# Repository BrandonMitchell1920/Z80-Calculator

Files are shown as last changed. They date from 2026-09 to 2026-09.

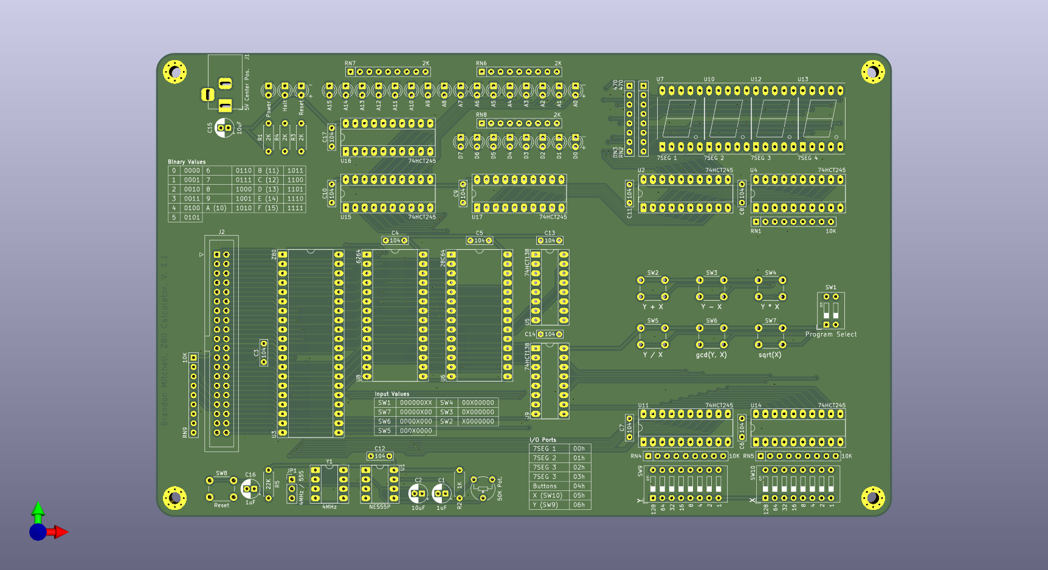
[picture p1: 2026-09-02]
images/PCB No Components.png

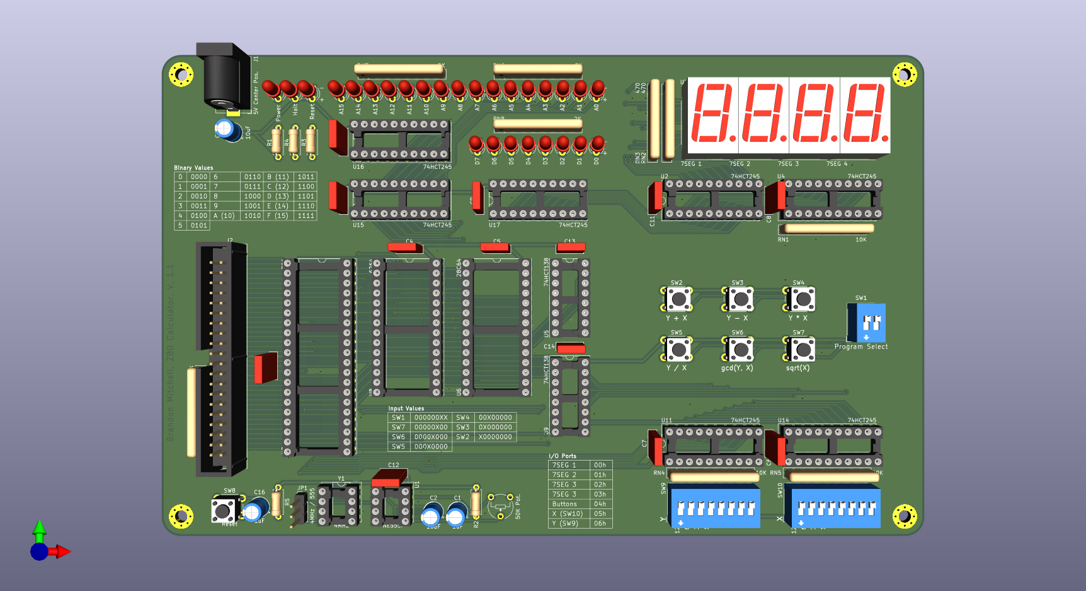
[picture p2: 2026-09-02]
images/PCB With Components.png

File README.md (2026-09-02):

# Z80 Calculator

This is a simple Z80 based calculator.  I have been doing various electronics projects
designed by other people and wanted to try making my own.  I figured a calculator
using the Z80 microprocessor would be a good choice as I had several of them on
hand and could reference other projects if needed.

## Features

The Z80 Caclulator has:

* 8K of RAM
* 8K of ROM
* 2 8-bit inputs (DIP switches)
* 6 push buttons
* Program select switch (software controlled)
* 4 seven segment displays (16-bit output)
* Expansion header for additional RAM or devices
* Blinkenlights!
* 555 timer for variable clock rate (useful for debugging)

Pretty basic, but this was more a learning exercise than anything.  Of the 8K ROM,
only a couple hundred bytes are used.  Combined with the program select switch,
it should be possible to load it up with three other programs.

The answers are displayed in hexadecimal so all operations on two eight bit numbers
would fit on the display.  The following operations are supported:

* Addition
* Subtraction
* Multiplication
* Division
* Greatest common denominator
* Square root

Only integer operations are supported, so division and square root are truncated.

## Programming

The Z80 Calculator has the following memory map:

* ROM: 0x0000 - 0x1FFF
* RAM: 0x2000 - 0x3FFF
* Unused: 0x4000 - 0xFFFF

I/O addresses are the following:

* 7SEG 1: 0x00
* 7SEG 2: 0x01
* 7SEG 3: 0x02
* 7SEG 4: 0x03
* Buttons + Program Select: 0x04
* DIP Switch X: 0x05
* DIP Switch Y: 0x06

The buttons and program select switch are mapped to the following bits of the byte
that you read back from their I/O address:

* SW1: Bits 0 and 1
* SW7: Bit 2
* SW6: Bit 3
* SW5: Bit 4
* SW4: Bit 5
* SW3: Bit 6
* SW2: Bit 7

All inputs are wired up to go high when enabled.  The seven segement displays are
also wired up to go high when a one is written to them.  Only one seven segment
display can be on at any time, and they won't stay on while other calculations
are occuring.  You can see an example of how this works in the provided source code.
There are also predefined values for the addresses and seven segment display values.

The idea with the program select switch was that on boot up, the code would check
what it was set to and jump to a different part of ROM.  However, it could be used
in other ways if multiple programs are not desired.

## BOM

Most of the parts can be had from Mouser except for the Z80 CPU.  Those are easy
enough to find on eBay.  Unicorn Electronics is also a good source for these parts
and is often cheaper than eBay or Mouser.  It might be possible to substitute 74HC
parts for the 74HCT, but I reccomend the latter.  74LS should be fine for any chip
that isn't driving an LED.  To use the 555 timer, you'll need a CMOS Z80.

For getting the PCB, I reccommend JLCPCB.  You can upload the included gerber files
to the site and just use their defaults, though change the color if you want.  Use the
cheapest shipping option (not DHL, FedEx, or UPS).

Component type     | Reference  | Description                                 | Quantity | Notes
------------------ | ---------- | ------------------------------------------- | -------- | --------------------------
PCB                |            | PCB                                         | 1        | JLCPCB, PCBWay
Capacitor          | C1,C16     | 1uF, electrolytic, 2mm lead spacing         | 2        | Could replace with ceramic
Capacitor          | C2,C15     | 10uF, electrolytic, 2mm lead spacing        | 2        | Could replace with ceramic
Capacitor          | C3,C4,C5,C6,C7,C8,C9,C10,C11,C12,C13,C14,C17 | 0.1uF, ceramic, 5mm lead spacing        | 13       |
LED                | D1,D2,D3,D4,D5,D6,D7,D8,D9,D10,D11,D12,D13,D14,D15,D16,D17,D18,D19,D20,D21,D22,D23,D24,D25,D26,D27  | 3mm lead spacing        | 27       | Consider mixing up the colors
Connector          | J1         | Barrel jack, 2.1mm                          | 1        |
Connector          | J2         | 2x20 shrouded pin header                    | 1        | Optional, used for expansion header
Connector          | JP1        | 1x3 pin header                              | 1        |
Resistor           | R1,R3,R4   | 2K ohm                                      | 3        |
Resistor           | R2         | 1K ohm                                      | 1        |
Resistor           | R5         | 22K ohm                                     | 1        |
Resistor Network   | RN1,RN4,RN5,RN9 | 10k ohm, 9 pin bussed                  | 4        |
Resistor Network   | RN2,RN3    | 470 ohm, 8 pin isolated                     | 2        | Could use normal resistors and bend leads
Resistor Network   | RN6,RN7,RN8| 2k ohm, 9 pin bussed                        | 3        |
Potentiometer      | RV1        | 50k ohm                                     | 1        |
Switch             | SW1        | DIP Switch 2x                               | 1        |
Switch             | SW2,SW3,SW4,SW5,SW6,SW7,SW8 | 6mm pushbutton             | 7        |
Switch             | SW9,SW10   | DIP Switch 8x                               | 2        |
IC                 | U1         | NE555P                                      | 1        | Other manufacturers are fine
IC                 | U2,U4,U11,U14,U15,U16,U17 | 74HCT245                     | 7        |
IC                 | U3         | Z80, CMOS, 4MHz                             | 1        |
IC                 | U5,U9      | 74HCT138                                    | 2        |
IC                 | U6         | 28C64 EEPROM                                | 1        | Can use 27C64
IC                 | U7,U10,U12,U13 | Seven segment, common cathode           | 4        | 
IC                 | U8         | 6264 RAM                                    | 1        | 
Oscillator         | Y1         | 4 MHz                                       | 1        | Could use a slower one or a faster one if the CPU supports higher speeds

## Building Firmware

I used RASM to assemble this.  Other assemblers would probably work, but the assembler 
directives may need to change.  Use the command "rasm_w64.exe -ob out.bin main.asm" to assemble.

## Misc

I wrote up a little post to my [blog](https://branmitc.blogspot.com/2026/09/homebrew-z80-computer.html) about designing and building this computer, if you
are interested.

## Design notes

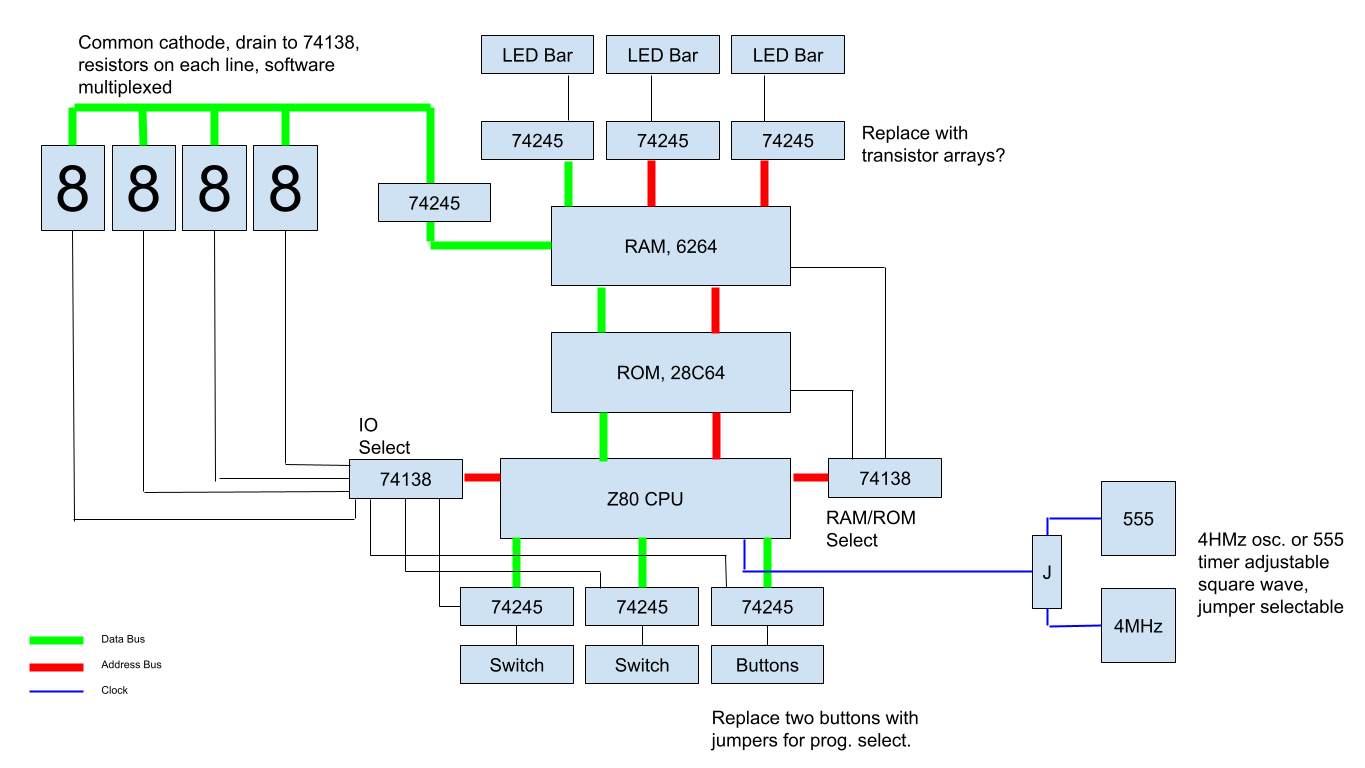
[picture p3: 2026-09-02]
images/Z80 Computer Block Diagram.png

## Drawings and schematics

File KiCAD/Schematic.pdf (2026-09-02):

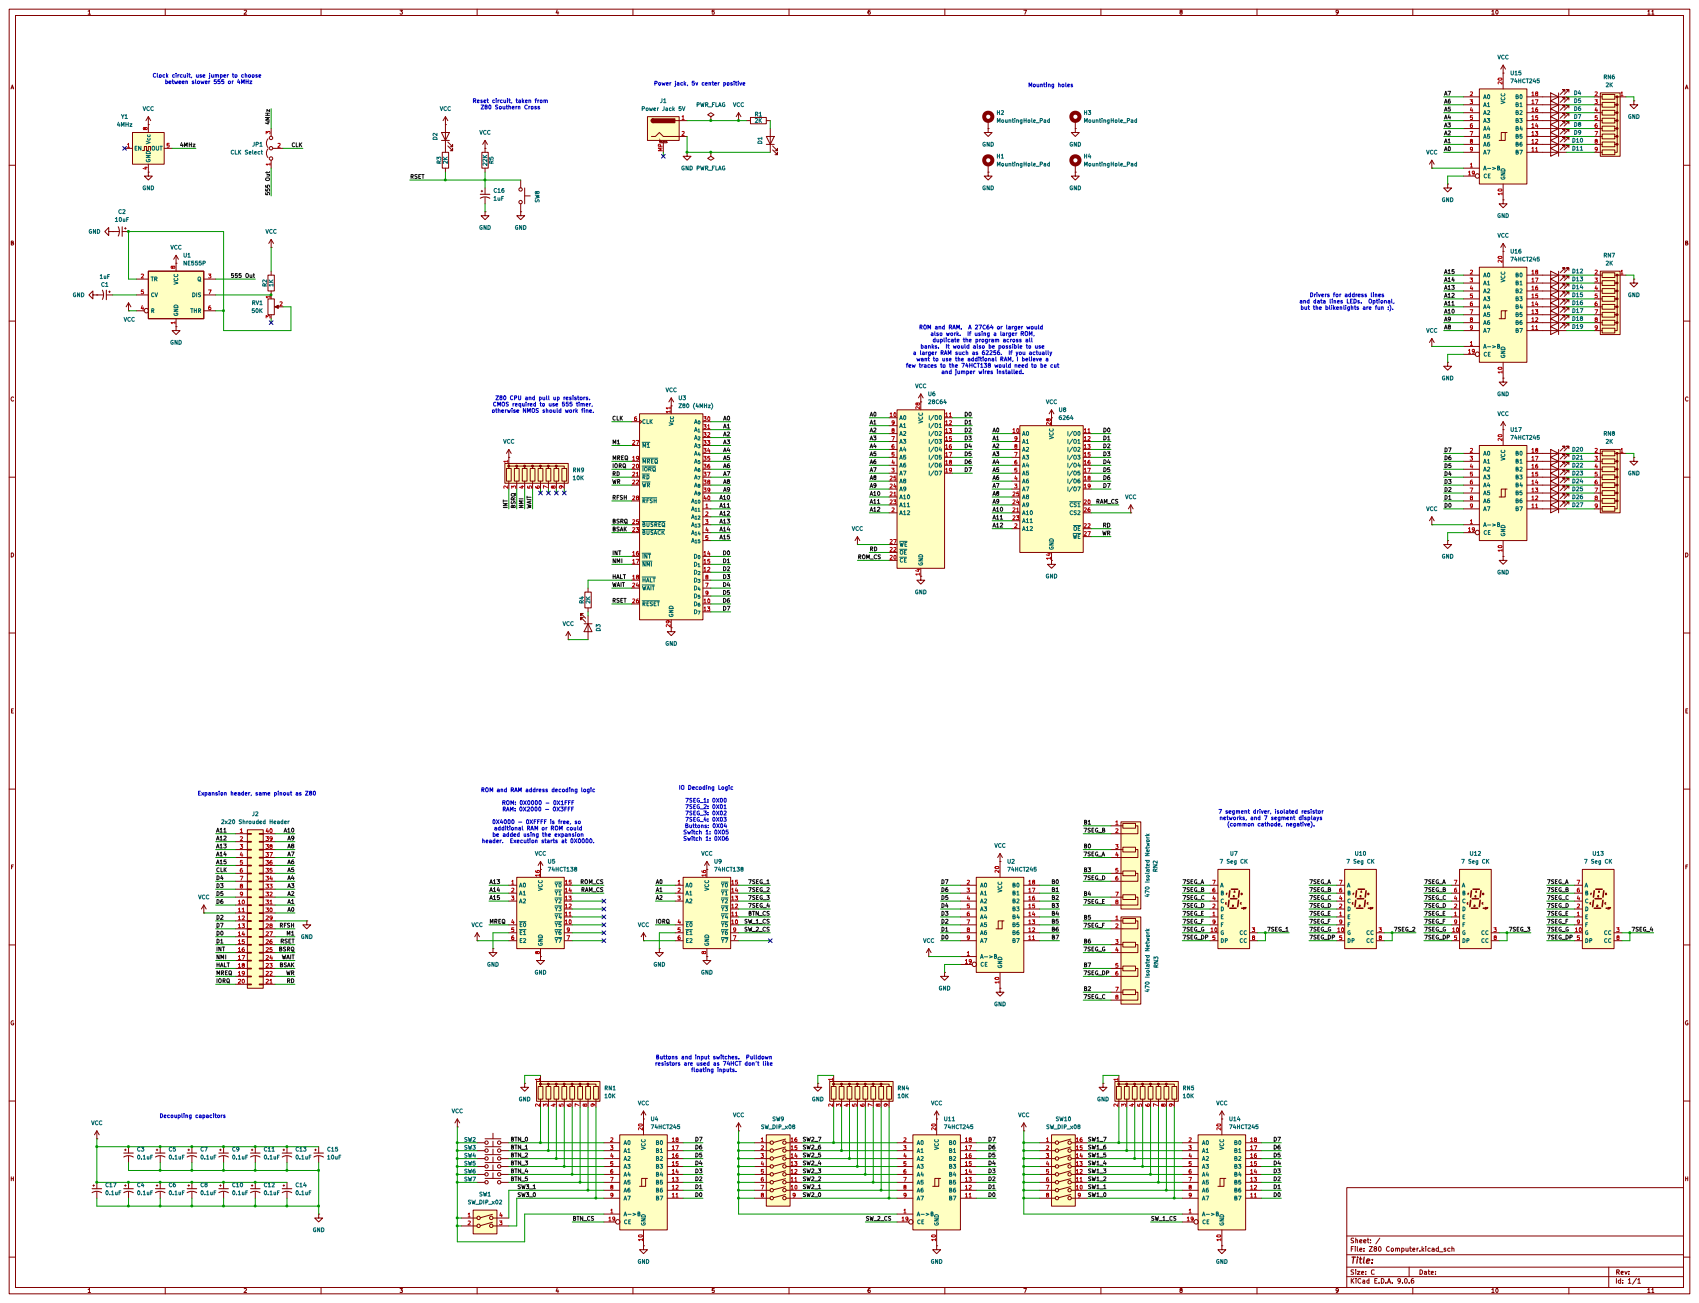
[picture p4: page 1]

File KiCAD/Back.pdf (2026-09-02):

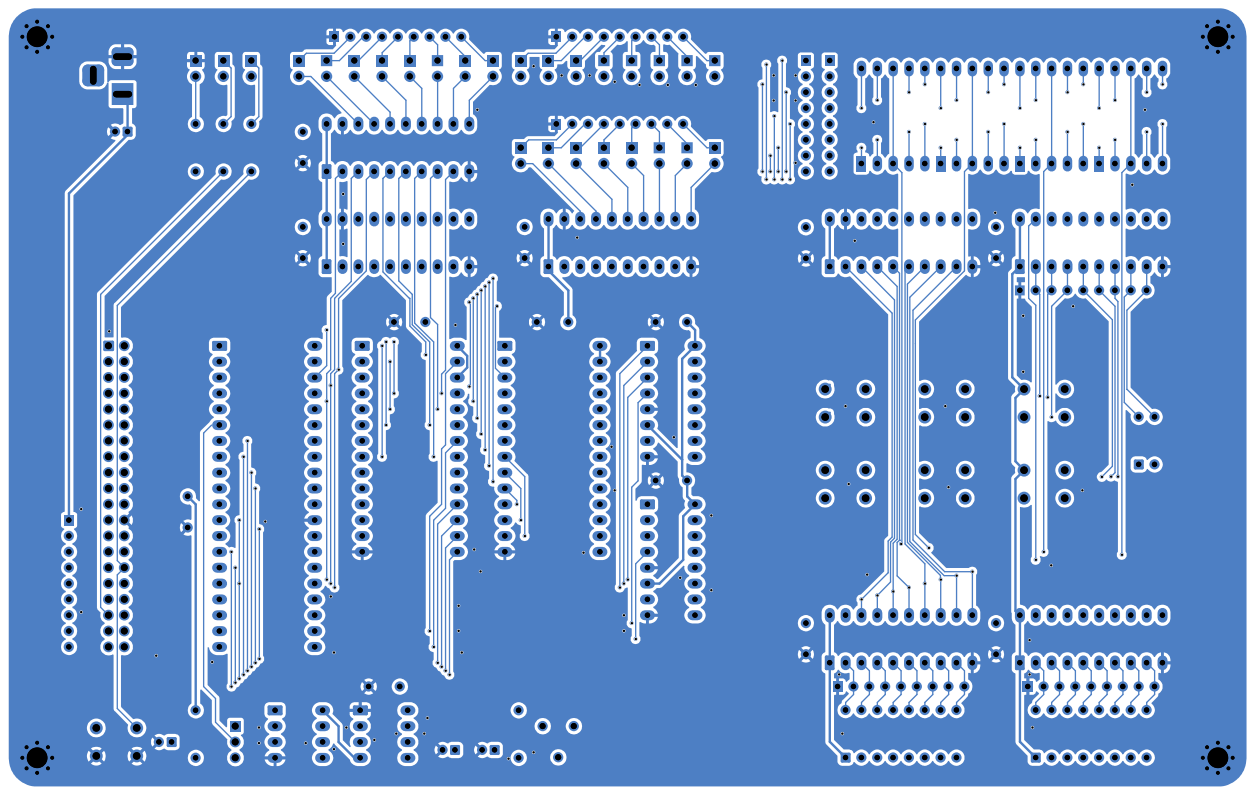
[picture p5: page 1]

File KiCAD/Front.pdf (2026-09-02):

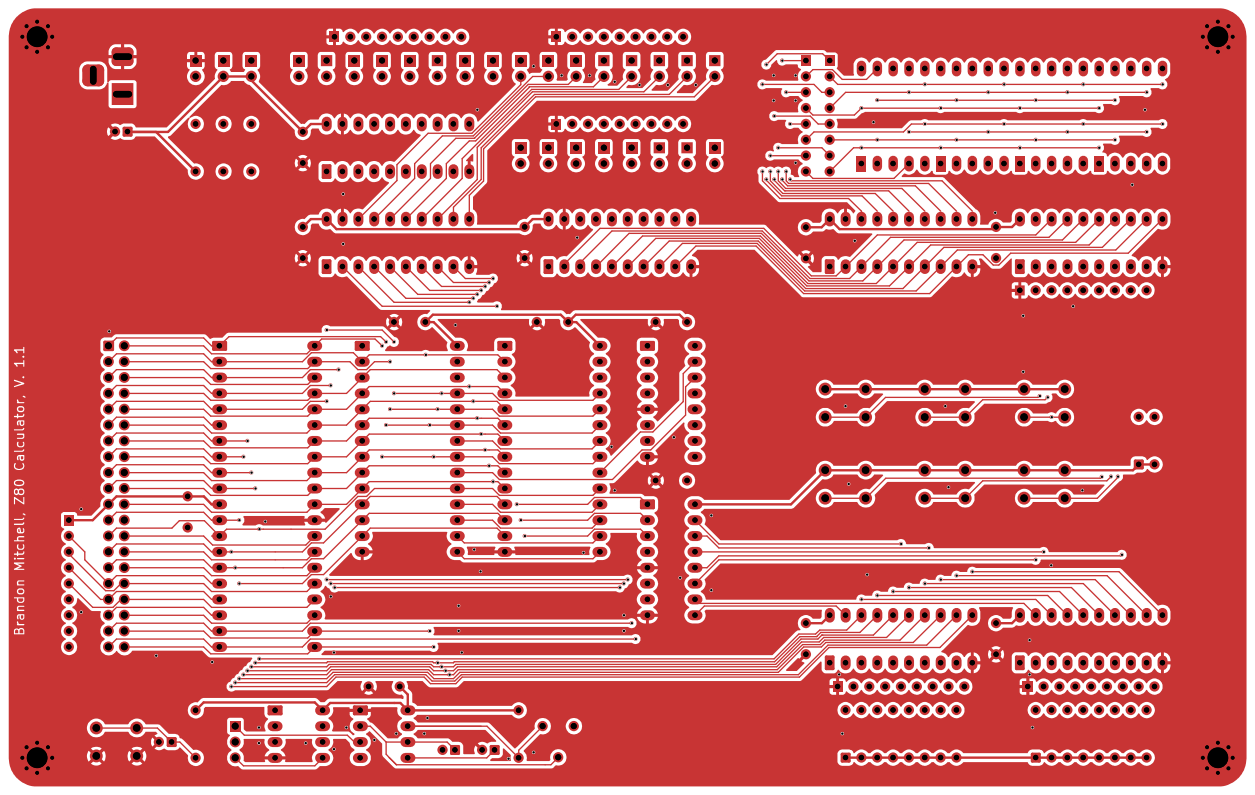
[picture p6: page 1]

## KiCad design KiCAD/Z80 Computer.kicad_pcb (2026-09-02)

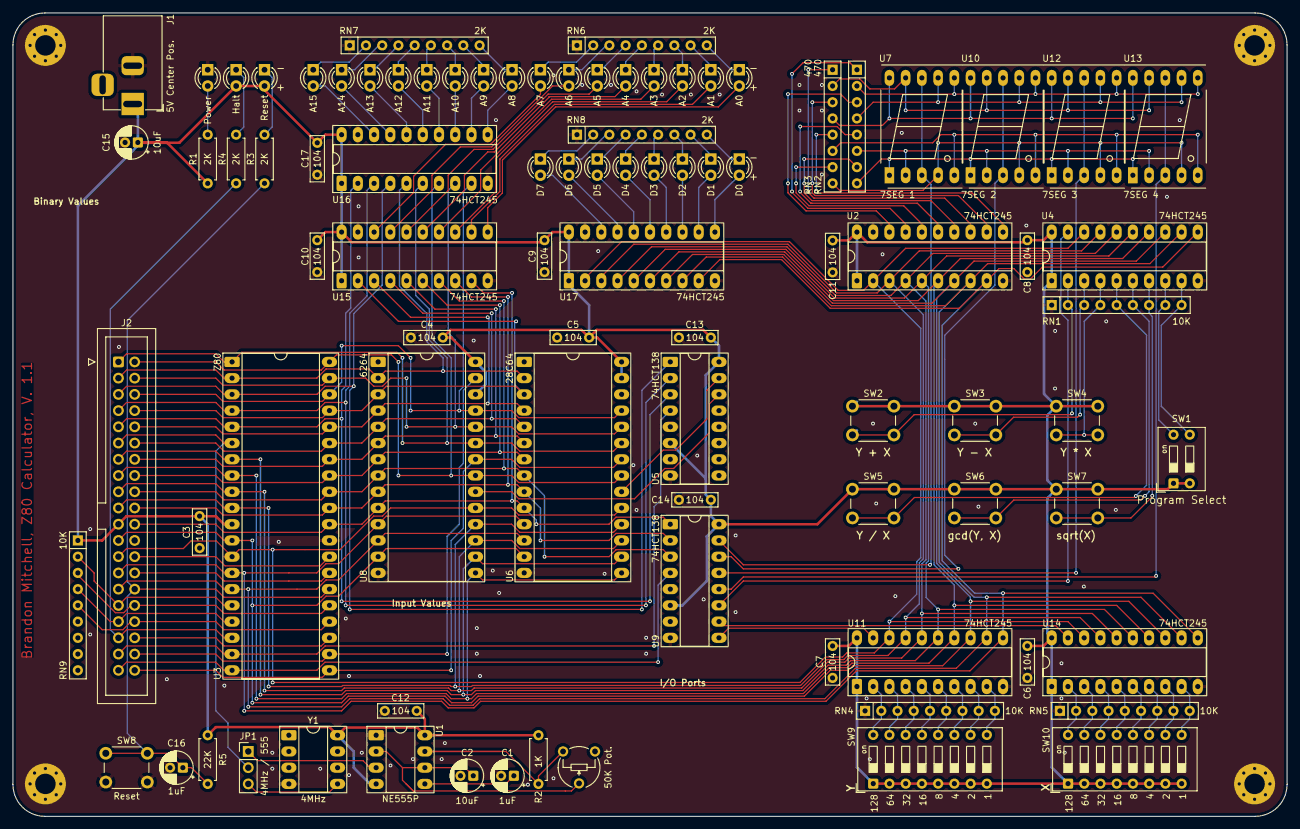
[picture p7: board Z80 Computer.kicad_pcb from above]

Board: 2 copper layers, 199.4 x 125.7 mm, 94 parts (0 on the bottom side), 145 nets.

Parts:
50K Pot.: 50K; Potentiometer_Piher_PT-6-V_Vertical
A0, A1, A2, A3, A4, A5, A6, A7, A8, A9, A10, A11, A12, A13, A14, A15: LED; LED_D3.0mm
C1, C16: 1uF; CP_Radial_D5.0mm_P2.00mm
C2, C15: 10uF; CP_Radial_D5.0mm_P2.00mm
C3, C4, C5, C6, C7, C8, C11, C12, C13, C14, C17: 0.1uF; C_Rect_L7.0mm_W2.0mm_P5.00mm
C9, C10: 104; C_Rect_L7.0mm_W2.0mm_P5.00mm
D0, D1, D2, D3, D4, D5, D6, D7: LED; LED_D3.0mm
H1, H2, H3, H4: MountingHole_Pad; MountingHole_3.2mm_M3_Pad_Via
Halt: LED; LED_D3.0mm
J1: 5V Center Pos.; BarrelJack_Horizontal
J2: 2x20 Shrouded Header; IDC-Header_2x20_P2.54mm_Vertical_Alt
JP1: 4MHz / 555; PinHeader_1x03_P2.54mm_Vertical
Power: LED; LED_D3.0mm
R1, R3, R4: 2K; R_Axial_DIN0207_L6.3mm_D2.5mm_P7.62mm_Horizontal
R2: 1K; R_Axial_DIN0207_L6.3mm_D2.5mm_P7.62mm_Horizontal
R5: 22K; R_Axial_DIN0207_L6.3mm_D2.5mm_P7.62mm_Horizontal
RN1, RN4, RN5, RN9: 10K; R_Array_SIP9
RN2, RN3: 100 Isolated Network; R_Array_SIP8
RN6, RN7, RN8: 2K; R_Array_SIP9
Reset: LED; LED_D3.0mm
SW1: Program Select; SW_DIP_SPSTx02_Slide_9.78x7.26mm_W7.62mm_P2.54mm
SW2: Y + X; SW_PUSH_6mm
SW3: Y - X; SW_PUSH_6mm
SW4: Y * X; SW_PUSH_6mm
SW5: Y / X; SW_PUSH_6mm
SW6: gcd(Y, X); SW_PUSH_6mm
SW7: sqrt(X); SW_PUSH_6mm
SW8: Reset; SW_PUSH_6mm
SW9, SW10: SW_DIP_x08; SW_DIP_SPSTx08_Slide_9.78x22.5mm_W7.62mm_P2.54mm
U1: NE555P; DIP-8_W7.62mm_Socket_LongPads
U2, U4, U11, U14, U15, U16, U17: 74HCT245; DIP-20_W7.62mm_Socket_LongPads
U3: Z80; DIP-40_W15.24mm_Socket_LongPads
U5, U9: 74HCT138; DIP-16_W7.62mm_Socket_LongPads
U6: 28C64; DIP-28_W15.24mm_Socket_LongPads
U7, U10, U12, U13: 7 Seg CK; 7SegmentLED_LTS6760_LTS6780
U8: 6264; DIP-28_W15.24mm_Socket_LongPads
Y1: 4MHz; DIP-8_W7.62mm_Socket_LongPads

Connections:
/4MHz: JP1.3 (B), Y1.5 (OUT)
/7SEG_1: U7.3 (CC), U7.8 (CC), U9.15 (~Y0)
/7SEG_2: U9.14 (~Y1), U10.3 (CC), U10.8 (CC)
/7SEG_3: U9.13 (~Y2), U12.3 (CC), U12.8 (CC)
/7SEG_4: U9.12 (~Y3), U13.3 (CC), U13.8 (CC)
/7SEG_A: RN2.4 (R2.2), U7.7 (A), U10.7 (A), U12.7 (A), U13.7 (A)
/7SEG_B: RN2.2 (R1.2), U7.6 (B), U10.6 (B), U12.6 (B), U13.6 (B)
/7SEG_C: RN3.8 (R4.2), U7.4 (C), U10.4 (C), U12.4 (C), U13.4 (C)
/7SEG_D: RN2.6 (R3.2), U7.2 (D), U10.2 (D), U12.2 (D), U13.2 (D)
/7SEG_DP: RN3.6 (R3.2), U7.5 (DP), U10.5 (DP), U12.5 (DP), U13.5 (DP)
/7SEG_E: RN2.8 (R4.2), U7.1 (E), U10.1 (E), U12.1 (E), U13.1 (E)
/7SEG_F: RN3.2 (R1.2), U7.9 (F), U10.9 (F), U12.9 (F), U13.9 (F)
/7SEG_G: RN3.4 (R2.2), U7.10 (G), U10.10 (G), U12.10 (G), U13.10 (G)
/555 Out: JP1.1 (A), U1.3 (Q)
/A0: J2.30, U3.30 (A_{0}), U6.10 (A0), U8.10 (A0), U9.1 (A0), U15.9 (A7)
/A1: J2.31, U3.31 (A_{1}), U6.9 (A1), U8.9 (A1), U9.2 (A1), U15.8 (A6)
/A2: J2.32, U3.32 (A_{2}), U6.8 (A2), U8.8 (A2), U9.3 (A2), U15.7 (A5)
/A3: J2.33, U3.33 (A_{3}), U6.7 (A3), U8.7 (A3), U15.6 (A4)
/A4: J2.34, U3.34 (A_{4}), U6.6 (A4), U8.6 (A4), U15.5 (A3)
/A5: J2.35, U3.35 (A_{5}), U6.5 (A5), U8.5 (A5), U15.4 (A2)
/A6: J2.36, U3.36 (A_{6}), U6.4 (A6), U8.4 (A6), U15.3 (A1)
/A7: J2.37, U3.37 (A_{7}), U6.3 (A7), U8.3 (A7), U15.2 (A0)
/A8: J2.38, U3.38 (A_{8}), U6.25 (A8), U8.25 (A8), U16.9 (A7)
/A9: J2.39, U3.39 (A_{9}), U6.24 (A9), U8.24 (A9), U16.8 (A6)
/A10: J2.40, U3.40 (A_{10}), U6.21 (A10), U8.21 (A10), U16.7 (A5)
/A11: J2.1, U3.1 (A_{11}), U6.23 (A11), U8.23 (A11), U16.6 (A4)
/A12: J2.2, U3.2 (A_{12}), U6.2 (A12), U8.2 (A12), U16.5 (A3)
/A13: J2.3, U3.3 (A_{13}), U5.1 (A0), U16.4 (A2)
/A14: J2.4, U3.4 (A_{14}), U5.2 (A1), U16.3 (A1)
/A15: J2.5, U3.5 (A_{15}), U5.3 (A2), U16.2 (A0)
/B0: RN2.3 (R2.1), U2.18 (B0)
/B1: RN2.1 (R1.1), U2.17 (B1)
/B2: RN3.7 (R4.1), U2.16 (B2)
/B3: RN2.5 (R3.1), U2.15 (B3)
/B4: RN2.7 (R4.1), U2.14 (B4)
/B5: RN3.1 (R1.1), U2.13 (B5)
/B6: RN3.3 (R2.1), U2.12 (B6)
/B7: RN3.5 (R3.1), U2.11 (B7)
/BSAK: J2.23, U3.23 (~BUSACK)
/BSRQ: J2.25, RN9.3 (R2), U3.25 (~BUSREQ)
/BTN_0: RN1.2 (R1), SW2.2, U4.2 (A0)
/BTN_1: RN1.3 (R2), SW3.2, U4.3 (A1)
/BTN_2: RN1.4 (R3), SW4.2, U4.4 (A2)
/BTN_3: RN1.5 (R4), SW5.2, U4.5 (A3)
/BTN_4: RN1.6 (R5), SW6.2, U4.6 (A4)
/BTN_5: RN1.7 (R6), SW7.2, U4.7 (A5)
/BTN_CS: U4.19 (CE), U9.11 (~Y4)
/CLK: J2.6, JP1.2 (C), U3.6 (CLK)
/D0: J2.14, U2.9 (A7), U3.14 (D_{0}), U4.11 (B7), U6.11 (I/O0), U8.11 (I/O0), U11.11 (B7), U14.11 (B7), U17.9 (A7)
/D1: J2.15, U2.8 (A6), U3.15 (D_{1}), U4.12 (B6), U6.12 (I/O1), U8.12 (I/O1), U11.12 (B6), U14.12 (B6), U17.8 (A6)
/D2: J2.12, U2.7 (A5), U3.12 (D_{2}), U4.13 (B5), U6.13 (I/O2), U8.13 (I/O2), U11.13 (B5), U14.13 (B5), U17.7 (A5)
/D3: J2.8, U2.6 (A4), U3.8 (D_{3}), U4.14 (B4), U6.15 (I/O3), U8.15 (I/O3), U11.14 (B4), U14.14 (B4), U17.6 (A4)
/D4: J2.7, U2.5 (A3), U3.7 (D_{4}), U4.15 (B3), U6.16 (I/O4), U8.16 (I/O4), U11.15 (B3), U14.15 (B3), U17.5 (A3)
/D5: J2.9, U2.4 (A2), U3.9 (D_{5}), U4.16 (B2), U6.17 (I/O5), U8.17 (I/O5), U11.16 (B2), U14.16 (B2), U17.4 (A2)
/D6: J2.10, U2.3 (A1), U3.10 (D_{6}), U4.17 (B1), U6.18 (I/O6), U8.18 (I/O6), U11.17 (B1), U14.17 (B1), U17.3 (A1)
/D7: J2.13, U2.2 (A0), U3.13 (D_{7}), U4.18 (B0), U6.19 (I/O7), U8.19 (I/O7), U11.18 (B0), U14.18 (B0), U17.2 (A0)
/HALT: J2.18, R4.1, U3.18 (~HALT)
/INT: J2.16, RN9.2 (R1), U3.16 (~INT)
/IORQ: J2.20, U3.20 (~IORQ), U9.4 (~E0)
/M1: J2.27, U3.27 (~M1)
/MREQ: J2.19, U3.19 (~MREQ), U5.4 (~E0)
/NMI: J2.17, RN9.4 (R3), U3.17 (~NMI)
/RAM_CS: U5.14 (~Y1), U8.20 (~CS1)
/RD: J2.21, U3.21 (~RD), U6.22 (~OE), U8.22 (~OE)
/RFSH: J2.28, U3.28 (~RFSH)
/ROM_CS: U5.15 (~Y0), U6.20 (~CE)
/RSET: C16.1, J2.26, R3.2, R5.2, SW8.1, U3.26 (~RESET)
/SW1_0: RN5.9 (R8), SW10.9, U14.9 (A7)
/SW1_1: RN5.8 (R7), SW10.10, U14.8 (A6)
/SW1_2: RN5.7 (R6), SW10.11, U14.7 (A5)
/SW1_3: RN5.6 (R5), SW10.12, U14.6 (A4)
/SW1_4: RN5.5 (R4), SW10.13, U14.5 (A3)
/SW1_5: RN5.4 (R3), SW10.14, U14.4 (A2)
/SW1_6: RN5.3 (R2), SW10.15, U14.3 (A1)
/SW1_7: RN5.2 (R1), SW10.16, U14.2 (A0)
/SW2_0: RN4.9 (R8), SW9.9, U11.9 (A7)
/SW2_1: RN4.8 (R7), SW9.10, U11.8 (A6)
/SW2_2: RN4.7 (R6), SW9.11, U11.7 (A5)
/SW2_3: RN4.6 (R5), SW9.12, U11.6 (A4)
/SW2_4: RN4.5 (R4), SW9.13, U11.5 (A3)
/SW2_5: RN4.4 (R3), SW9.14, U11.4 (A2)
/SW2_6: RN4.3 (R2), SW9.15, U11.3 (A1)
/SW2_7: RN4.2 (R1), SW9.16, U11.2 (A0)
/SW3_0: RN1.9 (R8), SW1.3, U4.9 (A7)
/SW3_1: RN1.8 (R7), SW1.4, U4.8 (A6)
/SW_1_CS: U9.10 (~Y5), U14.19 (CE)
/SW_2_CS: U9.9 (~Y6), U11.19 (CE)
/WAIT: J2.24, RN9.5 (R4), U3.24 (~WAIT)
/WR: J2.22, U3.22 (~WR), U8.27 (~WE)
GND: C1.2, C2.2, C3.2, C4.2, C5.2, C6.2, C7.2, C8.2, C9.2, C10.2, C11.2, C12.2, C13.2, C14.2, C15.2, C16.2, C17.2, H1.1, H2.1, H3.1, H4.1, J1.2, J2.29, Power.1 (K), RN1.1 (common), RN4.1 (common), RN5.1 (common), RN6.1 (common), RN7.1 (common), RN8.1 (common), SW8.2, U1.1 (GND), U2.10 (GND), U2.19 (CE), U3.29 (GND), U4.10 (GND), U5.5 (~E1), U5.8 (GND), U6.14 (GND), U8.14 (GND), U9.5 (~E1), U9.8 (GND), U11.10 (GND), U14.10 (GND), U15.10 (GND), U15.19 (CE), U16.10 (GND), U16.19 (CE), U17.10 (GND), U17.19 (CE), Y1.4 (GND)
unnamed: Power.2 (A), R1.1
unnamed: R3.1, Reset.1 (K)
unnamed: Halt.1 (K), R4.2
unnamed: A7.2 (A), U15.18 (B0)
unnamed: A7.1 (K), RN6.2 (R1)
unnamed: A6.2 (A), U15.17 (B1)
unnamed: A6.1 (K), RN6.3 (R2)
unnamed: A5.2 (A), U15.16 (B2)
unnamed: A5.1 (K), RN6.4 (R3)
unnamed: A4.2 (A), U15.15 (B3)
unnamed: A4.1 (K), RN6.5 (R4)
unnamed: A3.2 (A), U15.14 (B4)
unnamed: A3.1 (K), RN6.6 (R5)
unnamed: A2.2 (A), U15.13 (B5)
unnamed: A2.1 (K), RN6.7 (R6)
unnamed: A1.2 (A), U15.12 (B6)
unnamed: A1.1 (K), RN6.8 (R7)
unnamed: A0.2 (A), U15.11 (B7)
unnamed: A0.1 (K), RN6.9 (R8)
unnamed: A15.2 (A), U16.18 (B0)
unnamed: A15.1 (K), RN7.2 (R1)
unnamed: A14.2 (A), U16.17 (B1)
unnamed: A14.1 (K), RN7.3 (R2)
unnamed: A13.2 (A), U16.16 (B2)
unnamed: A13.1 (K), RN7.4 (R3)
unnamed: A12.2 (A), U16.15 (B3)
unnamed: A12.1 (K), RN7.5 (R4)
unnamed: A11.2 (A), U16.14 (B4)
unnamed: A11.1 (K), RN7.6 (R5)
unnamed: A10.2 (A), U16.13 (B5)
unnamed: A10.1 (K), RN7.7 (R6)
unnamed: A9.2 (A), U16.12 (B6)
unnamed: A9.1 (K), RN7.8 (R7)
unnamed: A8.2 (A), U16.11 (B7)
unnamed: A8.1 (K), RN7.9 (R8)
unnamed: D7.2 (A), U17.18 (B0)
unnamed: D7.1 (K), RN8.2 (R1)
unnamed: D6.2 (A), U17.17 (B1)
unnamed: D6.1 (K), RN8.3 (R2)
unnamed: D5.2 (A), U17.16 (B2)
unnamed: D5.1 (K), RN8.4 (R3)
unnamed: D4.2 (A), U17.15 (B3)
unnamed: D4.1 (K), RN8.5 (R4)
unnamed: D3.2 (A), U17.14 (B4)
unnamed: D3.1 (K), RN8.6 (R5)
unnamed: D2.2 (A), U17.13 (B5)
unnamed: D2.1 (K), RN8.7 (R6)
unnamed: D1.2 (A), U17.12 (B6)
unnamed: D1.1 (K), RN8.8 (R7)
unnamed: D0.2 (A), U17.11 (B7)
unnamed: D0.1 (K), RN8.9 (R8)
unnamed: C1.1, U1.5 (CV)
unnamed: 50K Pot..1, R2.1, U1.7 (DIS)
unnamed: 50K Pot..2, C2.1, U1.2 (TR), U1.6 (THR)
VCC: C3.1, C4.1, C5.1, C6.1, C7.1, C8.1, C9.1, C10.1, C11.1, C12.1, C13.1, C14.1, C15.1, C17.1, Halt.2 (A), J1.1, J2.11, R1.2, R2.2, R5.1, RN9.1 (common), Reset.2 (A), SW1.1, SW1.2, SW2.1, SW3.1, SW4.1, SW5.1, SW6.1, SW7.1, SW9.1, SW9.2, SW9.3, SW9.4, SW9.5, SW9.6, SW9.7, SW9.8, SW10.1, SW10.2, SW10.3, SW10.4, SW10.5, SW10.6, SW10.7, SW10.8, U1.4 (R), U1.8 (VCC), U2.1 (A->B), U2.20 (VCC), U3.11 (V_{CC}), U4.1 (A->B), U4.20 (VCC), U5.6 (E2), U5.16 (VCC), U6.27 (~WE), U6.28 (VCC), U8.26 (CS2), U8.28 (VCC), U9.6 (E2), U9.16 (VCC), U11.1 (A->B), U11.20 (VCC), U14.1 (A->B), U14.20 (VCC), U15.1 (A->B), U15.20 (VCC), U16.1 (A->B), U16.20 (VCC), U17.1 (A->B), U17.20 (VCC), Y1.8 (Vcc)

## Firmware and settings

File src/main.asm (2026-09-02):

; Z80 Calculator Program
; Brandon Mitchell
; rasm_w64.exe -ob out.bin main.asm
; http://rasm.wikidot.com/

; I/O addresses, 7 segement is output only, buttons and switches are input only
CS_7SEG_1       equ 0x00
CS_7SEG_2       equ 0x01
CS_7SEG_3       equ 0x02
CS_7SEG_4       equ 0x03
CS_BTN          equ 0x04
CS_SW_X         equ 0x05
CS_SW_Y         equ 0x06

; Used for checking which button was pressed, each button is tied to one data line
BIT_ADD         equ 7
BIT_SUB         equ 6
BIT_MUL         equ 5
BIT_DIV         equ 4
BIT_GCD         equ 3
BIT_SQRT        equ 2

; 7 6 5 4 3 2 1 0
; A B C D E F G DP
VAL_0           equ 0b11111100
VAL_1           equ 0b01100000
VAL_2           equ 0b11011010
VAL_3           equ 0b11110010
VAL_4           equ 0b01100110
VAL_5           equ 0b10110110
VAL_6           equ 0b10111110
VAL_7           equ 0b11100000
VAL_8           equ 0b11111110
VAL_9           equ 0b11110110
VAL_A           equ 0b11101110
VAL_B           equ 0b00111110
VAL_C           equ 0b10011100
VAL_D           equ 0b01111010
VAL_E           equ 0b10011110
VAL_F           equ 0b10001110

VAL_HYPHEN      equ 0b00000010

; Blank and r are used to display " Err", used when dividing by 0
VAL_BLANK       equ 0b00000000
VAL_r           equ 0b00001010

; Location of the display_ans values in ROM
VAL_START       equ 0x0200
SQRT_START      equ 0x0210

; 0000 - 1FFF is ROM, 2000 - 3FFF is RAM
RAM_START       equ 0x2000

; Memory locations of a view variables, used in display routine
NEG_RES         equ 0x2000
ANS_LOW         equ 0x2001
ANS_HIGH        equ 0x2002
DISP_SEG_1      equ 0x2003
DISP_SEG_2      equ 0x2004
DISP_SEG_3      equ 0x2005
DISP_SEG_4      equ 0x2006

; We want to store these values in ROM for use as a look up table
org             VAL_START
defb            VAL_0, VAL_1, VAL_2, VAL_3, VAL_4, VAL_5, VAL_6, VAL_7, VAL_8, VAL_9, VAL_A, VAL_B, VAL_C, VAL_D, VAL_E, VAL_F

; I didn't want to implement an actual square root, so store squares from 0 to 15
; We can then just consult this table to find which is closest to the input
org             SQRT_START
defb            0, 1, 4, 9, 16, 25, 36, 49, 64, 81, 100, 121, 144, 169, 196, 225

; Reset address to beginning of address space
org             0x0000



startup:
    ld          a, 0x00                 ; Clear neg bit
    ld          (NEG_RES), a

    ld          a, VAL_0                ; Screen should display all zeroes on start up
    ld          (DISP_SEG_1), a
    ld          (DISP_SEG_2), a
    ld          (DISP_SEG_3), a
    ld          (DISP_SEG_4), a



mainloop:
    in          a, (CS_BTN)             ; Read the buttons

    bit         BIT_ADD, a              ; Check which button was pressed
    jp          nz, addition

    bit         BIT_SUB, a
    jp          nz, subtraction

    bit         BIT_MUL, a
    jp          nz, multiplication

    bit         BIT_DIV, a
    jp          nz, divide

    bit         BIT_GCD, a
    jp          nz, gcd

    bit         BIT_SQRT, a
    jp          nz, square_root

    jp          display_ans             ; Display the answer



addition:
    ld          a, 0x00                 ; Clear neg bit
    ld          (NEG_RES), a

    in          a, (CS_SW_Y)            ; Read Y switch into A
    ld          h, 0x00                 ; Clear out H register (upper half of HL)
    ld          l, a                    ; L = A

    in          a, (CS_SW_X)            ; Read X switch into A
    ld          b, 0x00                 ; Clear out B register (upper half of BC)
    ld          c, a                    ; C = A

    add         hl, bc                  ; Needed to clear upper bytes as we are doing a 16 bit add

    ld          (ANS_LOW), hl           ; Store in RAM for later use

    jp          format_ans              ; Format the answer for later display



subtraction:
    ld          a, 0x00                 ; Clear neg bit
    ld          (NEG_RES), a

    in          a, (CS_SW_X)            ; Read X switch into A
    ld          c, a                    ; Move A value to C

    in          a, (CS_SW_Y)            ; Read Y switch into A

    cp          c                       ; Compare A and C
    jp          nc, subtraction_pos     ; If carry flag is not set, then A >= C, skip negative handling code

    ld          b, c                    ; Swap A with C before doing subtraction as A < C
    ld          c, a

    ld          a, 0x01                 ; Set neg bit
    ld          (NEG_RES), a

    ld          a, b                    ; Save C's value to A

subtraction_pos:
    sub         c                       ; A = A - C

    ld          (ANS_LOW), a            ; Save result for later
    ld          a, 0x00
    ld          (ANS_HIGH), a           ; The upper 8 bytes will always be 00 as the difference between two 8 bit
                                        ; values will always be an 8 bit value
    jp          format_ans              ; Format the answer for later display



multiplication:
    ld          a, 0x00                 ; Clear neg bit
    ld          (NEG_RES), a

    ld          l, a                    ; Clear out HL, will be used for adding
    ld          h, a

    in          a, (CS_SW_Y)            ; Read Y switch into A
    ld          b, 0x00                 ; Clear out B register (upper half of BC)
    ld          c, a                    ; C = A

    in          a, (CS_SW_X)            ; Read X switch into A

    cp          c                       ; Compare A and C
    jp          c, multiplication_loop  ; If carry flag is set, then A < C, go to loop

    ld          e, a                    ; Else, swap the values so the multiplication is faster
    ld          a, c
    ld          c, e

multiplication_loop:
    and         a                       ; Check if a is zero and exit loop if so
    jp          z, multiplication_end

    add         hl, bc                  ; Else, perform the add
    dec         a                       ; A is our loop counter, decrement it
    jp          multiplication_loop

multiplication_end:
    ld          (ANS_LOW), hl           ; Store in RAM for later use

    jp          format_ans              ; Format the answer for later display



divide:
    ld          a, 0x00                 ; Clear neg bit
    ld          (NEG_RES), a

    in          a, (CS_SW_X)            ; Read X switch into A

    and         a                       ; If it is zero, display an error
    jp          z, format_err           ; Can't divide by zero

    ld          c, a                    ; Move A value to C

    in          a, (CS_SW_Y)            ; Read Y switch into A

    ld          e, 0x00                 ; Used to store our answer

divide_loop:
    cp          c,                      ; A < C, stop division
    jp          c, divide_end

    sub         c                       ; A = A - C
    inc         e                       ; Increment our answer

    jp          divide_loop

divide_end:
    ld          a, e                    ; Load answer into A register
    ld          (ANS_LOW), a            ; Save result in RAM for later
    ld          a, 0x00                 ; The upper byte will always be 00
    ld          (ANS_HIGH), a

    jp          format_ans              ; Format the answer for later display



gcd:                                    ; Euclid's algorithm using subtraction
    ld          a, 0x00                 ; Clear neg bit
    ld          (NEG_RES), a

    in          a, (CS_SW_X)            ; Read X switch into A
    ld          c, a                    ; Move A value to C

    in          a, (CS_SW_Y)            ; Read Y switch into A
    ld          e, a                    ; Move A value to E

    and         a                       ; Test if E is zero
    jp          z, gcd_end              ; If so, skip to end, C is the answer

    ld          a, c                    ; Check if C is zero
    and         a
    jp          z, gcd_e_end            ; Skip to end and load E as answer

gcd_loop:
    ld          a, c                    ; Load C into A ...
    cp          e                       ; ... so we can compare it to E

    jp          z, gcd_end              ; C == E, we have our answer

    jp          nc, gcd_greater_than    ; C >= E

    ld          a, e                    ; Load E into A so we can perform the subtraction
    sub         c                       ; A = A - C
    ld          e, a                    ; E = A

    jp          gcd_loop

gcd_greater_than:
    ld          a, c                    ; Load E into A so we can perform the subtraction
    sub         e                       ; A = A - E
    ld          c, a                    ; C = A

    jp          gcd_loop

gcd_e_end:
    ld          c, e

gcd_end:
    ld          a, c                    ; Load answer into A register
    ld          (ANS_LOW), a            ; Save result for later
    ld          a, 0x00                 ; The upper byte will always be 00
    ld          (ANS_HIGH), a

    jp          format_ans              ; Format the answer for later display



square_root:
    ld          a, 0x00                 ; Clear neg bit
    ld          (NEG_RES), a

    in          a, (CS_SW_X)            ; Read X switch into A

    ld          b, 0x00                 ; Clear out B, upper half of BC
    ld          c, 15                   ; Highest possible int

square_root_loop:
    ld          hl, SQRT_START          ; Load in our ROM start value
    add         hl, bc                  ; Add to it our offset

    cp          (HL)                    ; Perform the comparision
    jp          nc, square_root_end     ; A >= (HL), we have our answer

    dec         c                       ; Decrement our offset and try again

    jp          square_root_loop

square_root_end:
    ld          a, c                    ; Load answer into A register
    ld          (ANS_LOW), a            ; Save result in RAM for later
    ld          a, 0x00                 ; The upper byte will always be 00    
    ld          (ANS_HIGH), a

    jp          format_ans              ; Format the answer for later display



format_err:
    ld          a, VAL_BLANK            ; Display " Err" for divide by 0
    ld          (DISP_SEG_1), a         ; Load appropriate values into RAM

    ld          a, VAL_E
    ld          (DISP_SEG_2), a

    ld          a, VAL_r
    ld          (DISP_SEG_3), a
    ld          (DISP_SEG_4), a

    jp          display_ans             ; Display the answer



format_ans:
    ld          b, 0x00                 ; B is used in getting the RAM offset, need to clear it

    ld          a, (ANS_LOW)            ; Load in the lower half of the answer
    and         0x0F                    ; We want the lower nibble for use as an offset

    ld          hl, VAL_START           ; Load in our ROM address
    ld          c, a                    ; and move the offset to C
    add         hl, bc                  ; and add to get the ROM address

    ld          a, (hl)                 ; Load the correct value
    ld          (DISP_SEG_4), a         ; and save it for later display

    ld          a, (ANS_LOW)            ; Perform same steps with upper nibble
    rrca        4                       ; Rotate right four times to isolate upper nibble
    and         0x0F

    ld          hl, VAL_START
    ld          c, a
    add         hl, bc

    ld          a, (hl)
    ld          (DISP_SEG_3), a

    out         (CS_7SEG_3), a

    ld          a, (ANS_HIGH)
    and         0x0F

    ld          hl, VAL_START
    ld          c, a
    add         hl, bc

    ld          a, (hl)
    ld          (DISP_SEG_2), a

    ld          a, (NEG_RES)            ; Check if neg bit is set
    and         a

    jp          nz, format_ans_neg      ; Skip logic for finding hex value, just show hyphen if negative

    ld          a, (ANS_HIGH)           ; Otherwise, perform same lookup logic
    rrca        4
    and         0x0F

    ld          hl, VAL_START
    ld          c, a
    add         hl, bc

    ld          a, (hl)
    ld          (DISP_SEG_1), a

    jp          display_ans

format_ans_neg:

    ld          a, VAL_HYPHEN           ; Load a hyphen into the first digit
    ld          (DISP_SEG_1), a

    jp          display_ans



display_ans:
    ld          a, (DISP_SEG_1)         ; Load first character and display it
    out         (CS_7SEG_1), a

    ld          a, (DISP_SEG_2)
    out         (CS_7SEG_2), a

    ld          a, (DISP_SEG_3)
    out         (CS_7SEG_3), a

    ld          a, (DISP_SEG_4)
    out         (CS_7SEG_4), a

    jp          mainloop
